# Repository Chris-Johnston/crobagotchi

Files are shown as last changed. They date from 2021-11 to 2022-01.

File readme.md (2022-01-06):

# Crobagotchi

Raise your own _virtual_ crow!

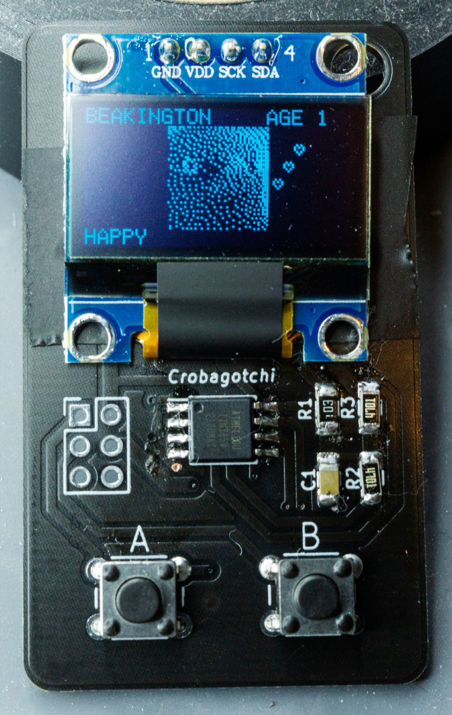
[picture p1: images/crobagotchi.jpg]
Image of the assembled board.


## What?



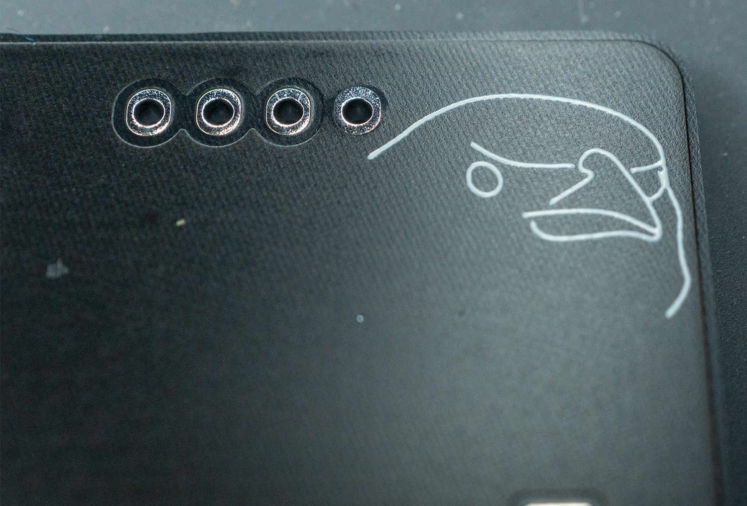
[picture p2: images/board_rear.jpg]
Back image of the board.


_Crobagotchi_ combines [Tamagotchi] with the [Crow of Judgement] (also referred to as a "Crob").

It's a portable handheld virtual pet which runs on an ATTiny85 and uses a SSD1306 OLED display
powered by a coin cell battery. The custom boards were designed using KiCad and [svg2mod], and the sprite work was done with Aseprite, GIMP, and [image2cpp].

## Why?

[Last year I made a PCB Crow of Judgement](https://github.com/Chris-Johnston/CrowOfJudgement), and this year I wanted to iterate on that. Eventually, I got the idea to make a knockoff Tamagotchi, and so I figured this would be a great time to do so.

Image of the Crow of Judgement from 2020.

[I still did make a simpler ornament this year, in the shape of an snowflake.](https://github.com/Chris-Johnston/snowflake-ornament) A lof of the board design is similar, it also uses ATTiny85.

## What else?

Battery life was a key concern, and so for this project I put a fair bit of time in to make sure
that wouldn't be a problem.

- Data is saved to EEPROM, so if the battery dies the state is preserved.
- Features of the ATTiny85 are disabled when unused, like the ADC.
- I use the deep sleep mode combined with the Watchdog Timer Interrupt to track realtime seconds (ticks once every 8 seconds), so that real time gets tracked as the device is sleeping.
- The SSD1306 is shut off as well during sleep to conserve power.

The other big issue was flash storage. The ATTiny85 has 8k of flash, which is largest offered.
I did not implement any compression for sprite bitmaps, which for each byte represents 8 vertical pixels. The 48x48 pixel image of the crow is 288 bytes, there were several times when testing where I used literally every last byte available in flash.

This code is pretty messy, I have not put much effort into cleaning it up as that was not a concern.

### SSD1306 Trouble

My experience with the SSD1306 with ATTiny85 was interesting. I tried a few libraries over time, and eventually settled with [Tiny4kOLED]. This one offered a sensible library that introduce extra fluff, like a menu that I'd never use?

Most importantly, I found that there was a bit-bang i2c implementation available where I could
reassign the pins. This was very important, because I had already ordered boards which relied
on a different pinout (PCBWay took a solid month to order), and I didn't want to disconnect
the display each time I reflashed it.

I copied this bitbang implementation and modified it to use the pins I specified.

Turns out there was more than one modification I'd make to this library. It included a 6x8 px font
which was great, but there were characters that I didn't use. Because of this, I modified
this font to add extra symbols that I'd use elsewhere, without having to add more to the flash.

## Pictures / Assembly Instructions

Here's the board fully assembled:

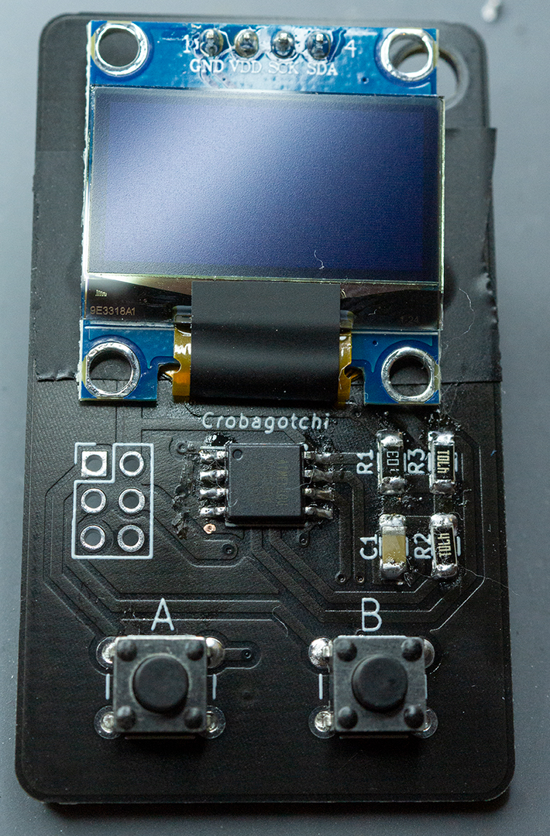
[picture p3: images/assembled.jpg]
Fully assembled crobagotchi.


Mind the flux and stray bits of q-tip used to clean it up.

1. First, unless already soldered, solder the ATTiny85 to the board.
To do this, I like to start by tinning pin 1, placing the IC in the right spot,
and sticking the IC in place. Then, doing the rest of the pins isn't much extra effort. Any extra solder can be removed with solder wick.

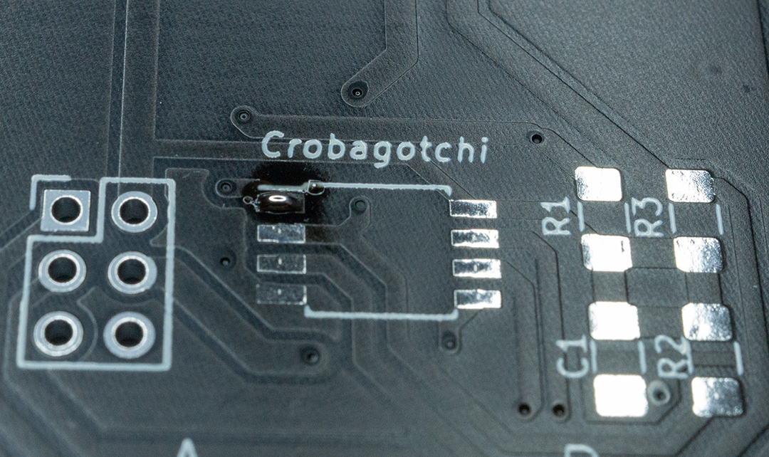
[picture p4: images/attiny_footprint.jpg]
Image of the attiny85 footprint
    

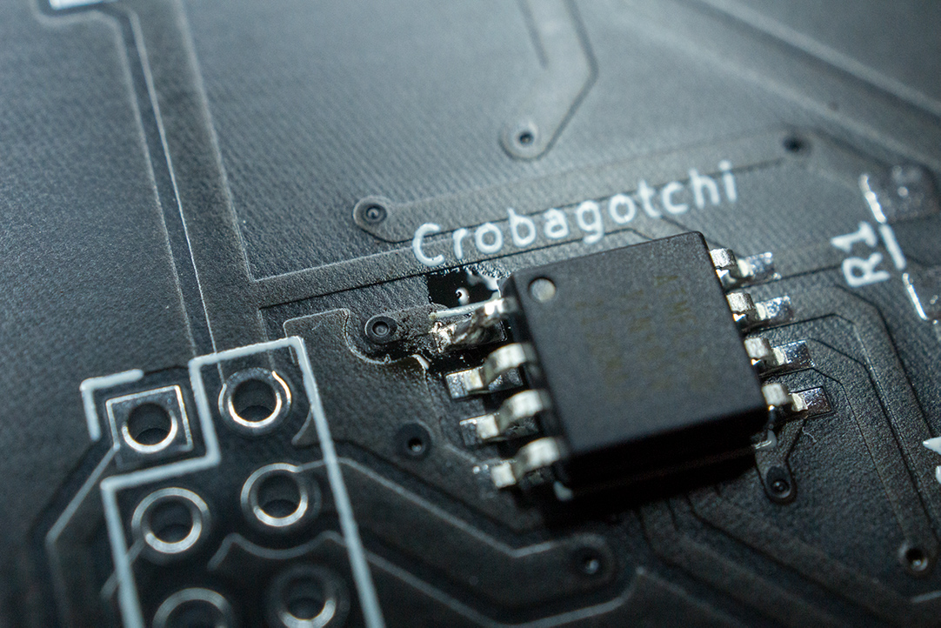
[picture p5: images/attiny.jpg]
Image of the soldered attiny85
    

2. Then solder the surface mount components.

    | Label | Value |
    | -- | -- |
    | C1 | 0.1 uF 1206 Capacitor |
    | R1 | 10k 1206 Resistor |
    | R2, R3 | 4.7k 1206 Resistor |

    I use a similar method, where I tin one side, place the part, solder that side down, and then solder the remaining side.

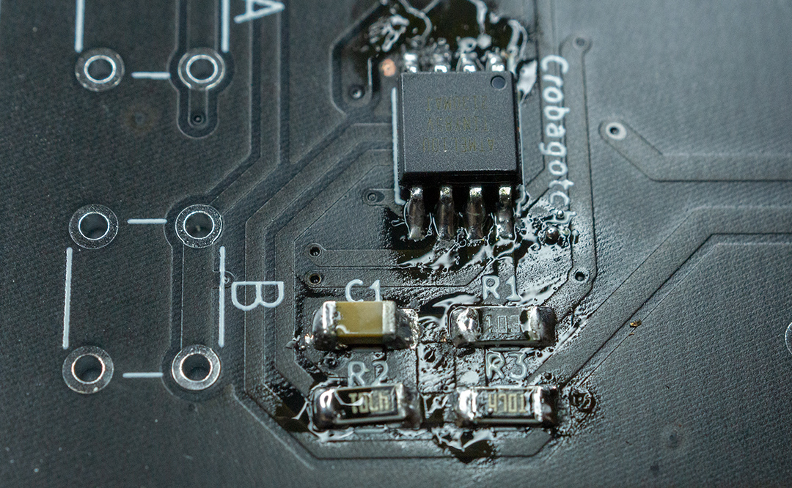
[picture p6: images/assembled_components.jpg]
Assembled surface mount parts
    

3. Then, install the 6mm push buttons. These are straightforward.

4. Install the battery holder. The square side is the positive terminal on the battery holders I used. **This must go on before the display!**

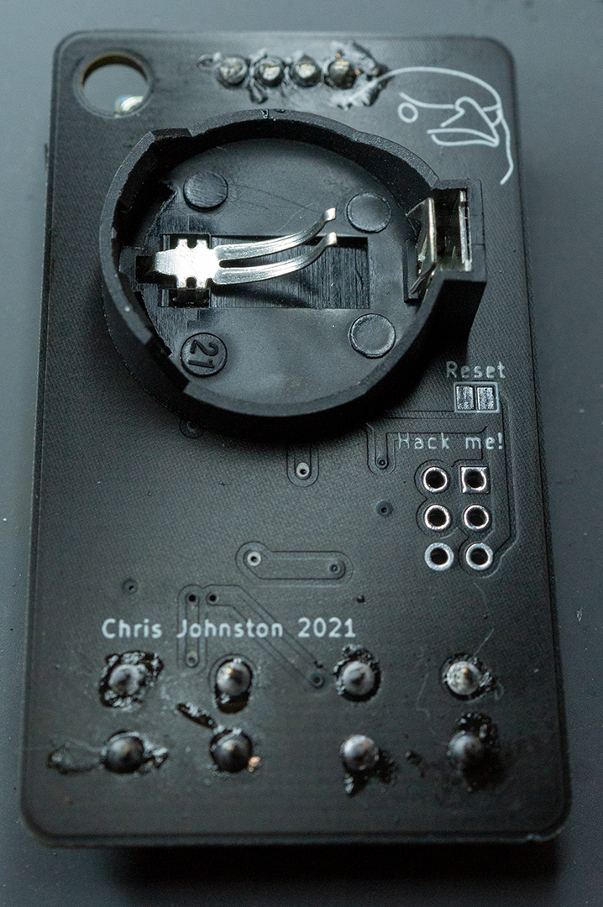
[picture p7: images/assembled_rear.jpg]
Image of the battery holder on the back.
    

    Be sure to clip the longer (and very sharp) pins of the battery holder.

    Before installing the display, I added some electrical tape to cover the battery contacts. This is so that it doesn't accidentally touch the display.

5. Install the display. There is some gap between the board and the display, and so I tilt the display a bit.

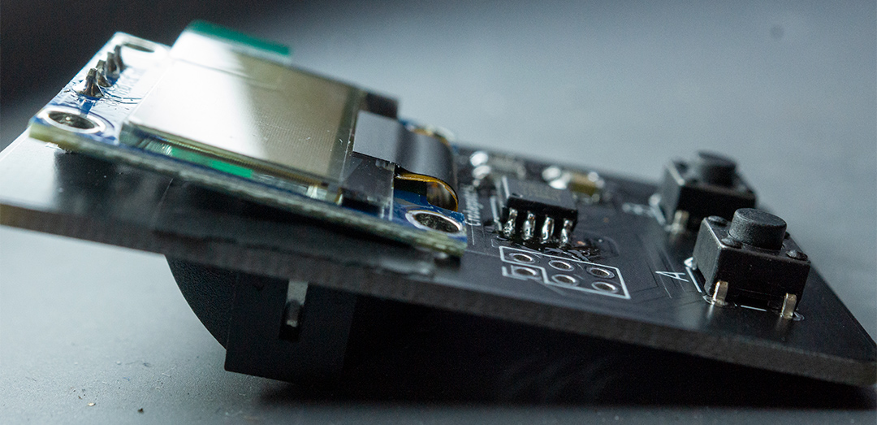
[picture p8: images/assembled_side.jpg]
Image of the display.
    

6. Finally, I used rubbing alcohol and q-tips to help clean up some of the flux.

7. To program the board, if it isn't already, I used a typical 6 pin USB AVR programmer **running at 3.3 volts**. While the ATTiny85 can run at 5v, the screen cannot. An [Arduino as ISP](https://www.arduino.cc/en/Tutorial/BuiltInExamples/ArduinoISP) can work great too.

    Because I didn't want pins sticking up the entire time, I could jam the pins at
    an angle to help a bit.

    When programming you'll need to do a few things:
      - Install ATTiny85 support via the board manager using https://github.com/damellis/attiny
      - Set the clock to "Internal 1 MHz" in the board settings
      - Click "burn bootloader" to set the clock speed

    Then, upload the firmware to the board.

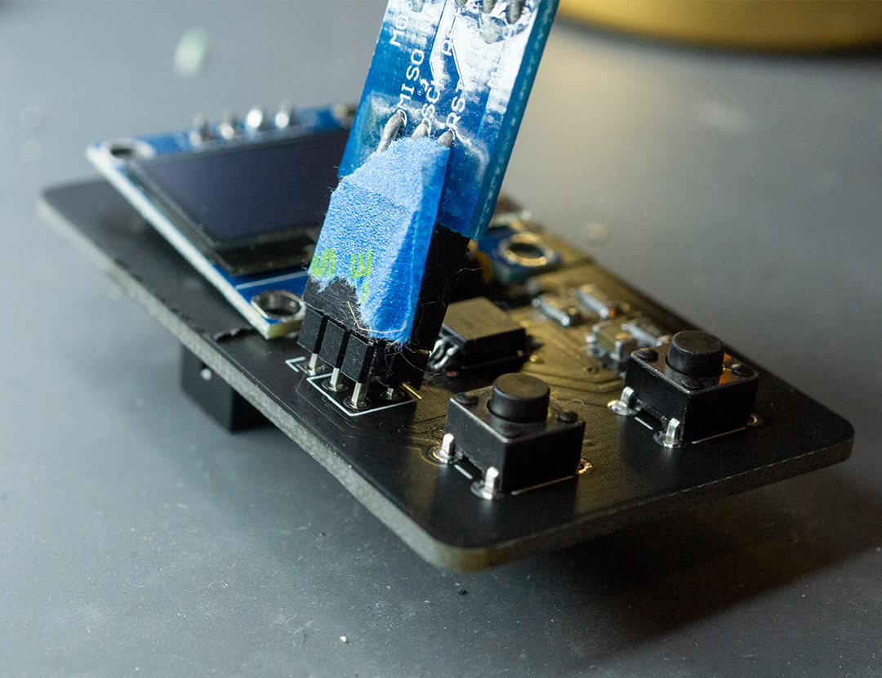
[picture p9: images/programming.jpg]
Image of programming the board.
    

8. Finally I could stick the battery in.

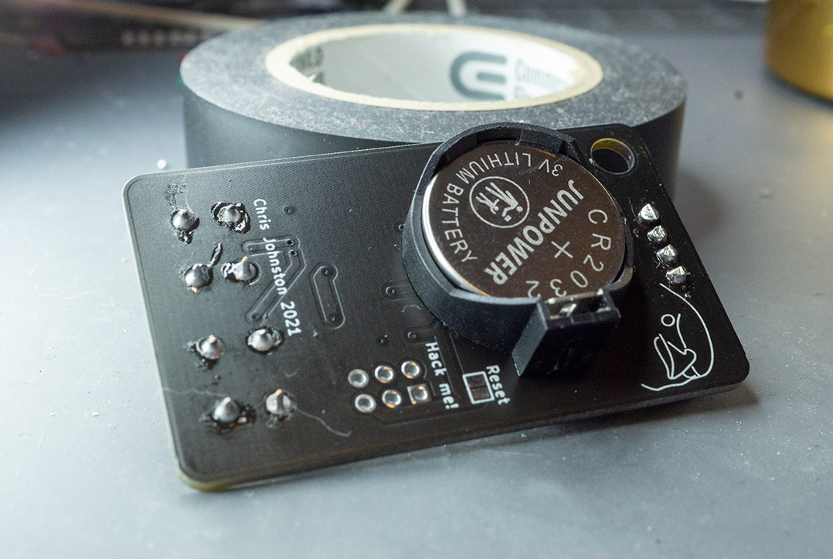
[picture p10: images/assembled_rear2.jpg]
Image of the back of the board.
    

[Tamagotchi]: https://en.wikipedia.org/wiki/Tamagotchi
[Crow of Judgement]: https://knowyourmeme.com/memes/crow-of-judgement
[svg2mod]: https://github.com/svg2mod/svg2mod
[image2cpp]: https://javl.github.io/image2cpp/
[Tiny4kOLED]: https://github.com/datacute/Tiny4kOLED

## Instructions

On first boot, a new Crob will be created with a randomly selected name.
You'll want to feed and play with it every day using the buttons to wake up
the device from sleep.

If for any reason you need a new Crob, hold the A + B buttons for a moment until a menu displays. Hold A in that menu, and you'll get a new crow.

If the battery dies all of your progress will be saved in the internal EEPROM.
The reset jumper on the back (don't solder it!) can be used in case something
crashes.

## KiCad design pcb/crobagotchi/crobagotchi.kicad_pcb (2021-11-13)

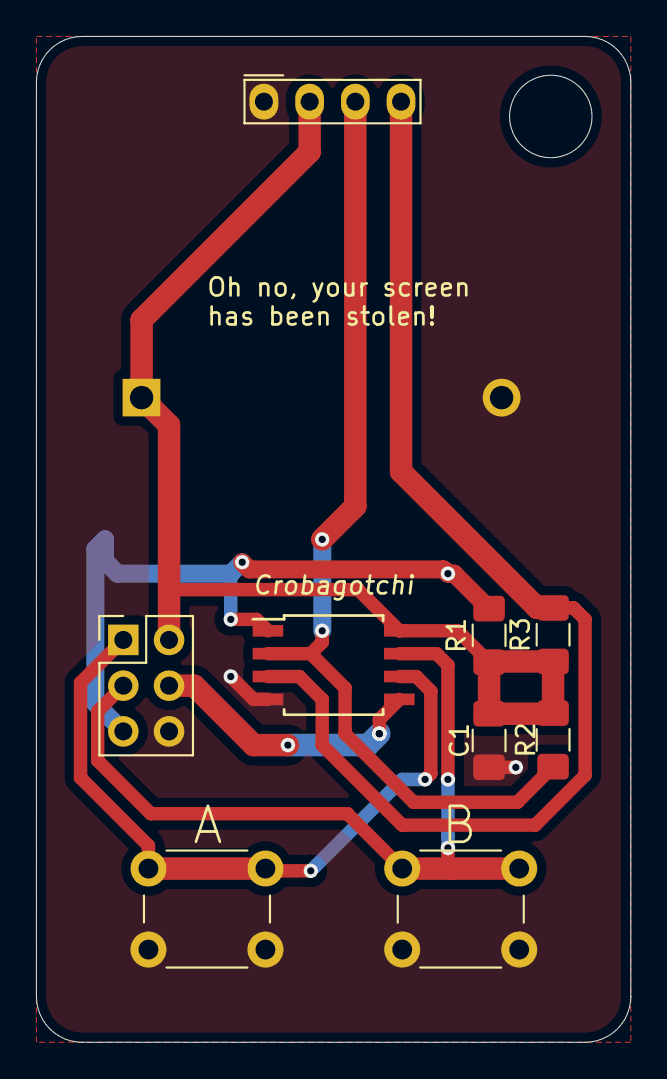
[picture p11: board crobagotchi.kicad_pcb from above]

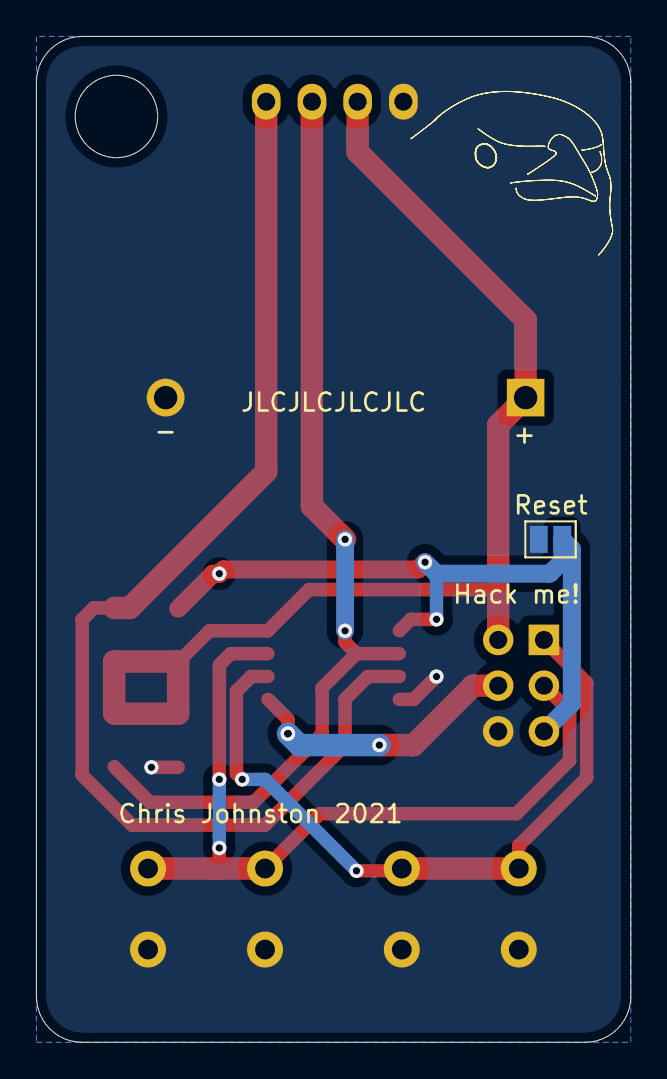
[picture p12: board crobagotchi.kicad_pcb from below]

Board: 2 copper layers, 33.0 x 55.9 mm, 12 parts (3 on the bottom side), 8 nets.

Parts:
BT1: Battery; BatteryHolder_ComfortableElectronic_CH273-2450_1x2450
Brd1: SSD1306; 128x64OLED
C1: 1uf; C_1206_3216Metric_Pad1.42x1.75mm_HandSolder
J1: AVR-ISP-6; PinHeader_2x03_P2.54mm_Vertical
R1: 10k; R_1206_3216Metric_Pad1.42x1.75mm_HandSolder
R2, R3: 4.7K; R_1206_3216Metric_Pad1.42x1.75mm_HandSolder
SW1: SW_Push; SolderJumper-2_P1.3mm_Open_Pad1.0x1.5mm
SW2, SW3: SW_Push; SW_PUSH_6mm
U1: ATtiny85V-10SU; SOIJ-8_5.3x5.3mm_P1.27mm
svg2mod: G***; kicad_vectorcrob

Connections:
GND: BT1.2, Brd1.1, C1.2, J1.6, SW1.2, SW2.2, SW3.2, U1.4
VCC: BT1.1, Brd1.2, C1.1, J1.2, R1.1, R2.1, R3.1, U1.8
button_option: J1.1, SW2.1, U1.6
button_select: J1.3, SW3.1, U1.7
disp_scl: Brd1.3, R2.2, U1.2
disp_sda: Brd1.4, R3.2, U1.3
mosi: J1.4, U1.5
rst: J1.5, R1.2, SW1.1, U1.1

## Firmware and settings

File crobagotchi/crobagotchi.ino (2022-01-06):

// Crobagotchi
// Definitely not inspired by any late 90's early 2000's toy

#include "crobgame.h"
#include "crob.h"
// #include "ssd1306.h"
// #include "nano_gfx.h"
#include "sprites.h"

#define BITBANG_SCL PB3
#define BITBANG_SDA PB4

#include "Tiny4kOLED_bitbang_mod.h"
#include "font6x8caps_mod.h"

#include "EEPROM.h"
#include <avr/io.h>
#include <avr/sleep.h>
#include <avr/wdt.h>
#include <avr/power.h>

CrobGame game;

#define BUTTON_A 1
#define BUTTON_B 2

// extern const char TextNormal[] PROGMEM = "Normal";
// extern const char TextSleeping[] PROGMEM = "Sleeping";
// extern const char TextHappy[] PROGMEM = "Happy";
// extern const char TextHungry[] PROGMEM = "Hungry";
// extern const char TextSad[] PROGMEM = "Sad";
// extern const char TextDead[] PROGMEM = "Dead";

// #define DEBUG_WD
// #define DEBUG_SCREEN
// #define DEBUG_LED

// interrupt flags
// these are technically redundant
volatile bool pinInterrupt = false;
volatile bool watchdogInterrupt = false;

bool firstBoot = false;

// this actually counts every 8 seconds
// configured to use the 16mhz internal clock but I think the watchdog timer doesn't care
volatile uint64_t interaction_seconds_counter = 0;

void enableScreen()
{
  oled.begin(128, 64, sizeof(tiny4koled_init_128x64br), tiny4koled_init_128x64br);
  oled.clear();
  // oled.deactivateScroll();
  // oled.disableZoomIn();
  // oled.disableFadeOutAndBlinking();
  oled.setFont(FONT6X8CAPSMOD);
  oled.on();

  // ssd1306_128x64_i2c_init();
  // ssd1306_setContrast(250);
  // ssd1306_normalMode();
  // ssd1306_clearScreen();
  // ssd1306_setFixedFont(ssd1306xled_font6x8);
}

ISR(WDT_vect)
{
  wdt_reset();
  watchdogInterrupt = true;
  pinInterrupt = false;
  firstBoot = false;
  interaction_seconds_counter++;
}

ISR(PCINT0_vect)
{
  pinInterrupt = true;
  watchdogInterrupt = false;
  firstBoot = false;
}

EMPTY_INTERRUPT(ADC_vect);
EMPTY_INTERRUPT(ANA_COMP_vect);
EMPTY_INTERRUPT(EE_RDY_vect);
EMPTY_INTERRUPT(INT0_vect);
EMPTY_INTERRUPT(TIM0_COMPA_vect);
EMPTY_INTERRUPT(TIM1_COMPA_vect);
EMPTY_INTERRUPT(TIM1_OVF_vect);
EMPTY_INTERRUPT(USI_OVF_vect);
EMPTY_INTERRUPT(USI_START_vect);
EMPTY_INTERRUPT(BADISR_vect);


// ISR(BADISR_vect)
// {
//   firstBoot = false;
// }>

void handle_watchdog_interrupt()
{
#ifdef DEBUG_WD
  if (MCUSR & _BV(WDRF)) // MCU Status Register, Watchdog Reset Flag
  {
    // // ssd1306_128x64_i2c_init();
    // // question: does changing contrast impact the power draw?
    // ssd1306_setContrast(255);
    // ssd1306_setFixedFont(ssd1306xled_font6x8);
    // ssd1306_clearScreen();
    // ssd1306_printFixed(0, 24, "WATCH DOG", STYLE_NORMAL);
    // MCUSR = 0;
  }
#endif
}

void clear_interrupt()
{
  cli();
  // disable pin change
  GIMSK = 0; // General Interrupt Mask Register

  // clear the interrupt flag Register
  GIFR = 0;

  // do not have to clear the watchdog interrupts, because it should operate silently
  // and should reset in case of crash as well
  // I think this is casuing crashes after it goes to sleep and comes back

  // disable all WD stuff
    // WDTCR = _BV(WDCE) | _BV(WDE);
    wdt_reset();
    WDTCR |= _BV(WDCE); //  | _BV(WDE);
    WDTCR = 0;

    sei();
}

void setup()
{
#ifdef DEBUG_LED
  pinMode(0, OUTPUT);
  digitalWrite(0, 1);
  delay(1);
  digitalWrite(0, LOW);
  delay(50);
#endif
#ifdef DEBUG_WD
  handle_watchdog_interrupt();
#endif

  // we do not use ADC ever
  ADCSRA = 0; // ADC Control Status Register A (reg B does not have an enable bit)
  PRR &= 0b1110; // disable ADC
  pinMode(BUTTON_A, INPUT_PULLUP);
  pinMode(BUTTON_B, INPUT_PULLUP); // pb2 pb1

  // unreachable code
  //   if (watchdogInterrupt) // watchdog interrupt will reset
  //   {
  // #ifdef DEBUG_WD
  //     enableScreen();
  //     oled.setCursor(0, 0);
  //     oled.println("WD in setup()");
  //     oled.println((int)interaction_seconds_counter);
  //     delay(200);
  // #endif

  // #ifdef DEBUG_LED
  //     digitalWrite(0, 1);
  //     delay(5);
  //     digitalWrite(0, LOW);
  //     delay(1000);
  //     digitalWrite(0, 1);
  //     delay(5);
  //     digitalWrite(0, LOW);
  //     delay(1000);
  // #endif
  //     deepSleep();
  //   }

  pinInterrupt = false;
  watchdogInterrupt = false;
  interaction_seconds_counter = 0;

#ifdef DEBUG_SCREEN
  enableScreen();
  // splashScreen();
  // ssd1306_printFixed(0, 16, "fresh reboot", STYLE_NORMAL);
  oled.print(F("FRESH REBOOT!"));
  delay(1000);
#endif
  initData();
  firstBoot = true;

#ifdef DEBUG_SCREEN
  delay(5000);
#endif

  // this added 38 bytes, ouch!
  // 8k of flash is HARD
  // if (MCUSR & _BV(BORF)) // brown out reset flag
  // {
  //   enableScreen();
  //   oled.println(F("BAT"));
  //   delay(255);
  // }

  if (MCUSR)
  {
    enableScreen();
    oled.println(MCUSR);
  }

  MCUSR = 0;
}

void screen_off()
{
  oled.clear();
  oled.off();

  // ssd1306_normalMode();
  // ssd1306_clearScreen();
  // ssd1306_displayOff();
  // ssd1306_setContrast(255); // set a timer to reduce contrast over time
}

// configures interrupt handlers, shuts off the display, and goes into deep sleep
void deepSleep()
{
#ifdef DEBUG_LED
  digitalWrite(0, 0);
#endif

  set_sleep_mode(SLEEP_MODE_PWR_DOWN);
  sleep_enable();

  noInterrupts();

  GIFR = 0;

  // enable pin change interrupts
  GIMSK = (1 << PCIE);
  PCMSK |= (1 << PCINT2) | (1 << PCINT1);

  // watchdog timer
  // WDCE = Change enable
  // WDE = Enable WD
  // WDIE = Watchdog timeout interrupt enable (cleared each time)
  wdt_reset();
  WDTCR = _BV(WDCE) | _BV(WDE) | _BV(WDIE) | _BV(WDP3) | _BV(WDP0); // 8 sec


// power_adc_disable();
// power_timer0_disable();
// power_timer1_disable();
// power_usi_disable();
power_all_disable();
  // clear pin interrupts

  // wdt_reset(); // not necessary here
  interrupts();


  // this fixes the screen going away and immediately coming back
  // I think re-enabling interrupts immediately calls one of the ISRs
  watchdogInterrupt = false;
  pinInterrupt = false;

  // sleeps here
  sleep_cpu();
  sleep_disable();

  power_timer0_enable();

  // wake up
}

void splashScreen()
{
#ifdef OLDSPLASH
  // skip
  for (int i = 0; i < 4; i += 1)
  {
    oled.clear();
    oled.setCursor(30, i);
    oled.print(F("CROBAGOTCHI"));

    // oled.print("CLKPR ");
    // oled.print(CLKPR);
    // ssd1306_clearScreen();
    // ssd1306_printFixed(30, i, "CROBAGOTCHI", STYLE_NORMAL);
    delay(200);
  }
#endif
  // ssd1306_printFixed(30, 48, "Ding!", STYLE_NORMAL);

  // #ifdef DEBUG_SCREEN
  //   char buf[32] = {0};
  //   sprintf(buf, "CLKPR %d", CLKPR);
  //   ssd1306_printFixed(0, 8, buf, STYLE_NORMAL);
  //   delay(1000);
  // #endif
}

// void dumpStatus()
// {
//     oled.clear();
//     oled.print(F("Age: "));
//     oled.print(game.crob.age);
//     oled.print(F(" Health: "));
//     oled.print(game.crob.health);
//     oled.newLine();
//     oled.print(F("Happy: "));
//     oled.print(game.crob.happy);
//     // ssd1306_clearScreen();
//     // char buf[32] = {0};
//     // sprintf(buf, "Age: %d Health: %d", game.crob.age, game.crob.health);
//     // ssd1306_printFixed(0, 8, buf, STYLE_NORMAL);
//     // sprintf(buf, "Happy: %d", game.crob.happy);
//     // ssd1306_printFixed(0, 24, buf, STYLE_NORMAL);

//     delay(30000);
// }

// init from eeprom, this will resume stored status
void initData()
{
#ifdef DEBUG_SCREEN
  oled.setCursor(0, 0);
  // ssd1306_printFixed(0, 8, "getting data", STYLE_NORMAL);
  oled.println("GETTING DATA");

  auto checksum = EEPROM.read(39);
  oled.print("checksum: ");
  oled.println((int)checksum, 10);
  // delay(1000);
#endif

  auto freshData = game.LoadData();

  if (!freshData)
  {
#ifdef DEBUG_SCREEN
    // ssd1306_printFixed(0, 8, "init new data", STYLE_NORMAL);
    oled.println("INIT NEW DATA");
    delay(1000);
#endif

    game.StartNewGame();
    game.SaveData();
  }
  else
  {
#ifdef DEBUG_SCREEN
    // ssd1306_printFixed(0, 8, "using old data", STYLE_NORMAL);
    oled.println("USING OLD DATA");
    delay(1000);
#endif
  }
}

// 1 hour
#define SLEEP_THRESH (60 * 60 / 8)
// #define SLEEP_THRESH 2 // testing

// age increases every 120 min
#define AGE_THRESH (120 * 60 / 8)
// #define AGE_THRESH 2

// happy should decay by 75 every day
#define HAPPY_DECAY 144
// food should decay by 100 every day
#define FEED_DECAY 108

void on_resume()
{
  if (interaction_seconds_counter > 0 && !game.crob.getIsDead())
  {
    // decay by counter * 8
#ifdef DEBUG_SCREEN
    // char buf[32] = {0};
    // sprintf(buf, "Off Time: %d", interaction_seconds_counter);
    // ssd1306_printFixed(0, 32, buf, STYLE_NORMAL);
    oled.print("OFF TIME");
    oled.println((int)interaction_seconds_counter, 10);
    delay(5000);
#endif

    game.crob.isSleeping = interaction_seconds_counter > SLEEP_THRESH;

    // game.crob.health = game.crob.health - (interaction_seconds_counter / FEED_DECAY);
    game.crob.setHealth(game.crob.health - interaction_seconds_counter / FEED_DECAY);

    // game.crob.happy = game.crob.happy - (interaction_seconds_counter / HAPPY_DECAY);
    game.crob.setHappy(game.crob.happy - interaction_seconds_counter / HAPPY_DECAY);

    // allow overflow, that's funny
    game.crob.age += interaction_seconds_counter / AGE_THRESH;
  }
}

#define IDLE_TIME (15 * 1000)
#define DEBOUNCE_TIME (30)
#define MENU_DEBOUNCE (500)

unsigned long last_debounce_a = 0;
unsigned long last_debounce_b = 0;
unsigned long menu_debounce = 0;
bool last_state_a = false;
bool last_state_b = false;
bool last_menu = false;

// 0 closed
// 1 - feed
// 2 - play

int menu_option = 0;

#define RESET_HOLD 5 * 1000
#define LONG_RESET_HOLD 9 * 1000

unsigned long reset_hold_time = 0;

void reset_seq()
{
  if ((millis() - reset_hold_time) > RESET_HOLD)
  {
    oled.clear();
    // oled.println(F("WARNING!"));
    oled.println(F("HOLD A TO RESET"));

    auto timer = millis();
    bool delet = false;
    while ((millis() - timer) < LONG_RESET_HOLD)
    {
      clear_bot_line();
      oled.print((millis() - timer) / 1000);
      oled.setCursor(18, 7);

      // requring held down
      // reminder that buttons are inverted
      delet = !digitalRead(BUTTON_A) && digitalRead(BUTTON_B);
      if (delet)
      {
        oled.print(F("YES"));
      }
      else
      {
        oled.print(F("NO"));
      }

      delay(300);
    }

    if (delet)
    {
      oled.clear();
      oled.println(F(":( BYE"));
      delay(2000);

      game.StartNewGame();
      game.SaveData();

      draw_main_menu();
    }
    else
    {
      oled.clear();
      oled.println(F(":)"));
      delay(2000);

      draw_main_menu();
    }
  }
}

void draw_fry()
{
  // fill the screen

  // without loops this uses way more
  for (int x = 0; x < 120; x += 24)
    for (int y = 0; y < 64; y += 32)
      oled.bitmap(x, y / 8, x + 24, y / 8 + 3, epd_bitmap_fry);

  delay(3000);
}

void feed_seq()
{
  oled.clear();

  draw_fry();

  // oled.println(F("FEED SEQ"));
  // delay(3000);

  game.crob.isSleeping = false;
  // game.crob.health = min(255, game.crob.health + 50);
  game.crob.setHealth(game.crob.health + 120);
}

void play_seq()
{
  // play seq
        oled.clear();
        // I only have like, 70 bytes left
        oled.bitmap(0, 0, 48, 6, CHARACTER_SPRITE);
        delay(300);
        oled.clear();
        oled.bitmap(40, 2, 88, 8, CHARACTER_SPRITE);
        delay(300);
        oled.clear();
        oled.bitmap(80, 0, 128, 6, CHARACTER_SPRITE);
        delay(300);

        game.crob.isSleeping = false;
        // game.crob.happy = min(255, game.crob.happy + 50);
        game.crob.setHappy(game.crob.happy + 120);
}

void game_loop() // naming consistency, what's that?
{
  draw_main_menu();

  bool needsredraw = false;
  auto last_interaction_time = millis();
  // await button presses (might need to be smart and use interrupts instead of polling, not sure?)

  while (millis() < last_interaction_time + IDLE_TIME)
  {
    // draw status on display

    // debounce
    bool a = !digitalRead(BUTTON_A);
    bool b = !digitalRead(BUTTON_B);

    if (a != last_state_a)
    {
      last_debounce_a = millis();
    }
    if (b != last_state_b)
    {
      last_debounce_b = millis();
    }
    last_state_a = a;
    last_state_b = b;

    // reuse the same values
    if ((millis() - last_debounce_a) < DEBOUNCE_TIME)
    {
      a = false;
    }
    if ((millis() - last_debounce_b) < DEBOUNCE_TIME)
    {
      b = false;
    }

    if (a || b)
    {
      last_interaction_time = millis();
    }

    // handle reset
    if (a && b && reset_hold_time == 0)
    {
      reset_hold_time = millis();
      continue;
    }
    else if (a && b && reset_hold_time != 0)
    {
      reset_seq();
      last_interaction_time = millis();
      continue;
    }
    else
    {
      reset_hold_time = 0;
    }

    bool menu = b && !a;
    // debounce the menu
    if ((millis() - menu_debounce) < MENU_DEBOUNCE)
    {
      menu = false;
    }
    
    // move through menu
    else if (menu)
    {

      if (!game.crob.getIsDead())
      {
        needsredraw = true;
        menu_option += 1;
        menu_option %= 3;
      }
      else
      {
        menu_option = 0;
      }

      menu_debounce = millis();
    }

    last_menu = menu;


    if (needsredraw)
    {
      clear_bot_line();
      if (menu_option)
      {
        // oled.invertOutput(true);
        oled.print(F("MENU:"));
        // oled.invertOutput(false);
        oled.setCursor(40, 7);

        if (menu_option == 1)
        {
          oled.print(F("FEED"));
        }
        else if (menu_option == 2)
        {
          oled.print(F("PLAY"));
        }
      }
      else
      {
        draw_status();
      }
      needsredraw = false;
    }

    if (a && !b)
    {
      if (menu_option == 0)
      {
        continue;
      }
      else if (menu_option == 1)
      {
        feed_seq();
      }
      else if (menu_option == 2)
      {
        play_seq();
      }

      draw_main_menu();
      menu_option = 0;
    }

    // oled.setCursor(0, 0);

    // if (a)
    //   oled.println("A");
    // if (b)
    //   oled.println("B");
    // if (!a && !b)
    //   oled.println(" ");
  }
  // oled.clear();
  // oled.setCursor(0, 0);
  // oled.println("OFF");
  // delay(3000);
}

void draw_main_menu()
{
  // ssd1306_clearScreen();

  // 8 px at the top is for the name and age
  // char buf[128 / 5] = {0};
  // sprintf(buf, "%s - Age %d", game.crob.name, 123);
  // ssd1306_printFixed(0, 0, buf, STYLE_NORMAL);

  oled.clear();
  oled.setCursor(0, 0);
  oled.print(game.crob.name);
  // oled.print(F(" - Age: "));
  oled.setCursor(128 - 42, 0);
  // 4
  oled.print(F("AGE "));
  // 3
  oled.print(game.crob.age);

  // auto pet = ssd1306_createSprite(40, 48, 48, epd_bitmap_test);

  // 4 px margin

  // leaves a 40 px square in the center for the status
  // 128 / 2 = 64
  // 64 - 24 = 40 px from the side
  // nevermind bitmaps have to be multiples of 8
  // ssd1306_drawBitmap(40, 8 / 8, 48, 48, epd_bitmap_test);
  if (!game.crob.getIsDead())
  {
    oled.bitmap(40, 1, 88, 56 / 8, CHARACTER_SPRITE);

    if (game.crob.isSleeping || game.crob.GetStatus() == Status::Happy)
    {
      auto z = F("Z");
      if (game.crob.GetStatus() == Status::Happy)
      {
        z = F("^");
      }
      oled.setCursor(90, 4);
      oled.print(z);

      oled.setCursor(95, 3);
      oled.print(z);

      oled.setCursor(100, 2);
      oled.print(z);
    }
  }
  else
  {
    oled.setCursor(58, 3);
    oled.print(F("RIP"));
  }

  // delay(1000);
  // ssd1306_clearScreen();
  // drawBitMapIntScale(40, 8 / 8, 2, 24, 24, crow_24px);

  // 4 px margin

  // 8 px at the bottom is for the status indicator
  // sprintf(buf, "HUNGRY, DIRTY");
  // ssd1306_printFixed(8, 56, buf, STYLE_NORMAL);
  clear_bot_line();
  draw_status();

  // delay(3000);

  // draw_menu(0);
}

void clear_bot_line()
{
  oled.setCursor(0, 7);
  oled.clearToEOL();
}

void draw_status()
{
  // clear_bot_line();
  // oled.print("HUNGRY, DIRTY");
  // oled.print(F("STATUS: "));

  switch (game.crob.GetStatus())
  {
  case Status::Sad:
    oled.print(F("SAD"));
    break;
  case Status::Sleeping:
    oled.print(F("SLEEPING"));
    break;
  case Status::Happy:
    oled.print(F("HAPPY"));
    break;
  case Status::Dead:
    oled.print(F("DEAD"));
    break;
  case Status::Normal:
  default:
    oled.print(F("NORMAL"));
    break;
  }
}

// void draw_menu(int cursorIdx)
// {
//   oled.setCursor(8, 1);
//   oled.clearToEOL();
//   oled.println(F("MENU:"));

//   if (cursorIdx == 0)
//   {
//     oled.print(F("> "));
//   }
//   oled.println(F("FEED"));
//   oled.println(F("PLAY"));

//   // ssd1306_drawRect(20, 20, 108, 16);
//   // ssd1306_printFixed(21, 21, "MENU OPTION", STYLE_NORMAL);

//   // ssd1306_setColor(0);
//   // ssd1306_fillRect(0, 56, 128, 64);
//   // ssd1306_negativeMode();
//   // ssd1306_printFixed(8, 56, "MENU:", STYLE_NORMAL);
//   // ssd1306_positiveMode();
//   // ssd1306_printFixed(46, 56, "FEED", STYLE_NORMAL);
// }

void loop()
{
  if (pinInterrupt || firstBoot)
  {
    clear_interrupt();
    enableScreen();
    if (firstBoot)
    {
      splashScreen();
    }

    firstBoot = false;
    // game loop, exits when inactive for x amount of time
    splashScreen();

    on_resume();

    // now that I think about it, saving into eeprom really isn't necessary given
    // that variables are being preserved just fine
    // still is a nice QOL of thing in case the battery dies or if it crashes
    game.SaveData();

    game_loop();

    interaction_seconds_counter = 0;
  }

#ifdef DEBUG_WD
  if (watchdogInterrupt)
  {
    // don't need to do anything special here
    // already incrementing the sleep counter anyways
    // this will be applied on next pin interrupt
    enableScreen();
    oled.setCursor(0, 0);
    oled.println("WD in loop()");
    oled.println((int)interaction_seconds_counter);
    delay(200);
  }
#endif

  screen_off();
  deepSleep(); // pauses here
}

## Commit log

2021-11-07 add a bunch of hacky code
    [crobagotchi.kicad_pcb, crobagotchi.sch]
2021-11-07 8 second wd timer
2021-11-13 update pcb
    [crobagotchi.sch]
2021-11-13 add gerber files that were made
    [crobagotchi-B_Cu.gbr, crobagotchi-B_Mask.gbr, crobagotchi-B_SilkS.gbr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]
2021-12-01 messy commit of current changes
2021-12-09 fix bug where on sleep, it wakes up again
    [crobagotchi.ino]
2021-12-22 remove unused files
    [crobagotchi-B_Cu.gbr, crobagotchi-B_Mask.gbr, crobagotchi-B_SilkS.gbr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]
